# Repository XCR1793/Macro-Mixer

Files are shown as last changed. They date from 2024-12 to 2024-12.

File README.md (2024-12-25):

# Macro Mixer
A DIY Streamdeck alternative for a custom configurable macro board with dials, compatible with commercially available switches (Cherry MX Hotswappable). Reverse mounted under key lighting is also added for both debugging and aesthetics whilst allowing the top side of the board to remain clean and flush.

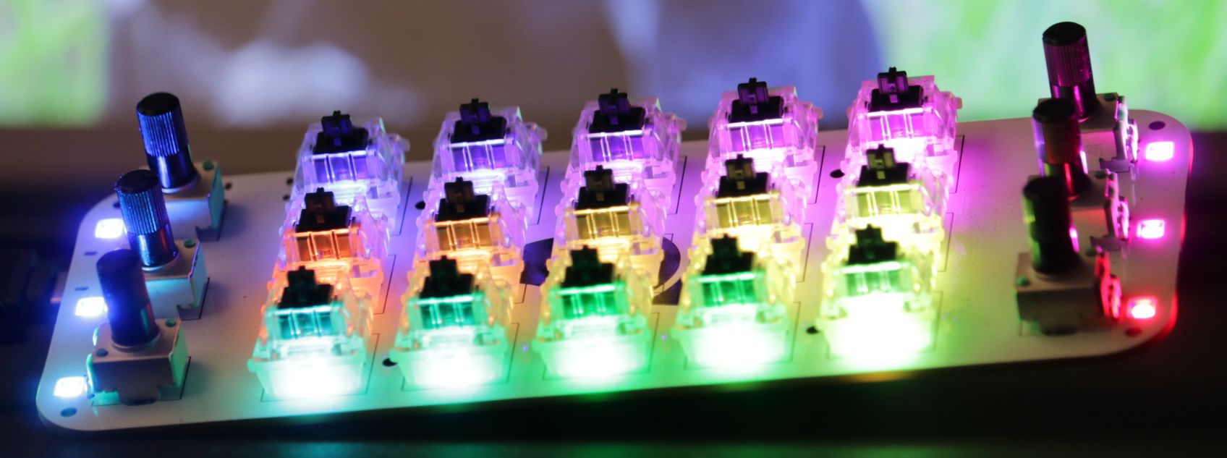
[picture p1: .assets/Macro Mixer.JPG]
Project_Image


## Features
* 15x Individually addressable n key rollover switches 
* 6x 12 bit resolution dials
* Addressable underglow lighting for every key and dial
* Easy Key assignment via the software

## [Hardware](/Hardware/README.md)
The case is 3D printed in white PLA plastic however other colour work too. The STLs and Steps are provided in the hardware folder.

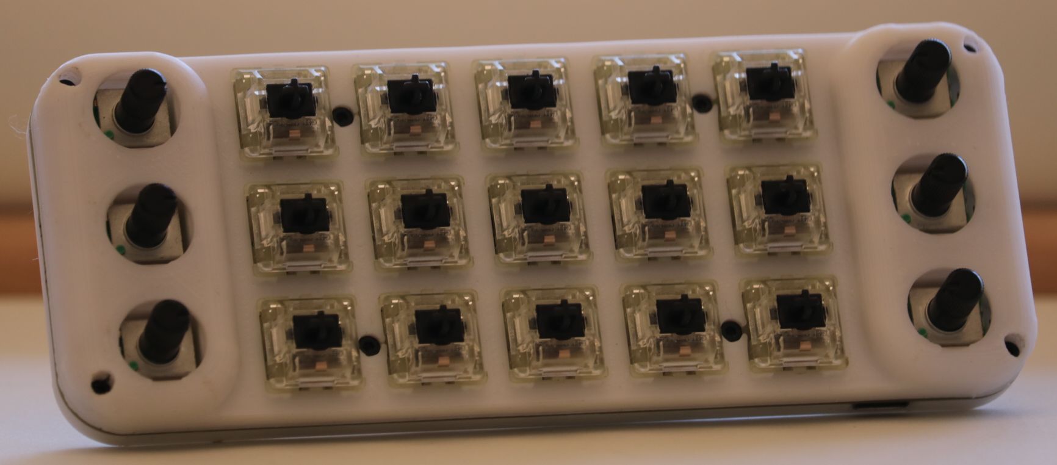
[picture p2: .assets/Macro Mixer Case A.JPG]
Hardware


## [Software](/Software/README.md)
Using PlatformIO and buildin ESP32 libraries, I have made an easy way to configure what keys are assigned to what key-combo.

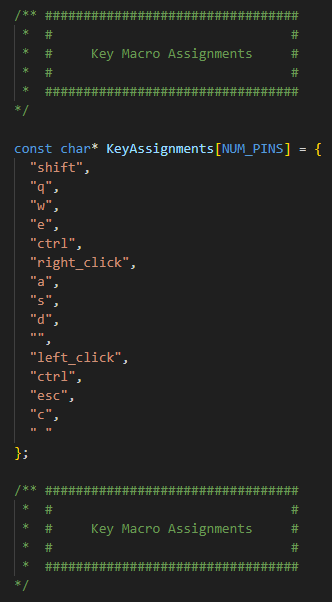
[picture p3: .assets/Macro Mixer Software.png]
Software


## [Embedded](/Embedded/README.md)
Although the currently fabricated PCB has some mistakes, I have modified the KiCAD files to account for this. The embedded circuit is a relatively dense board requiring a steady hand and hotplate.

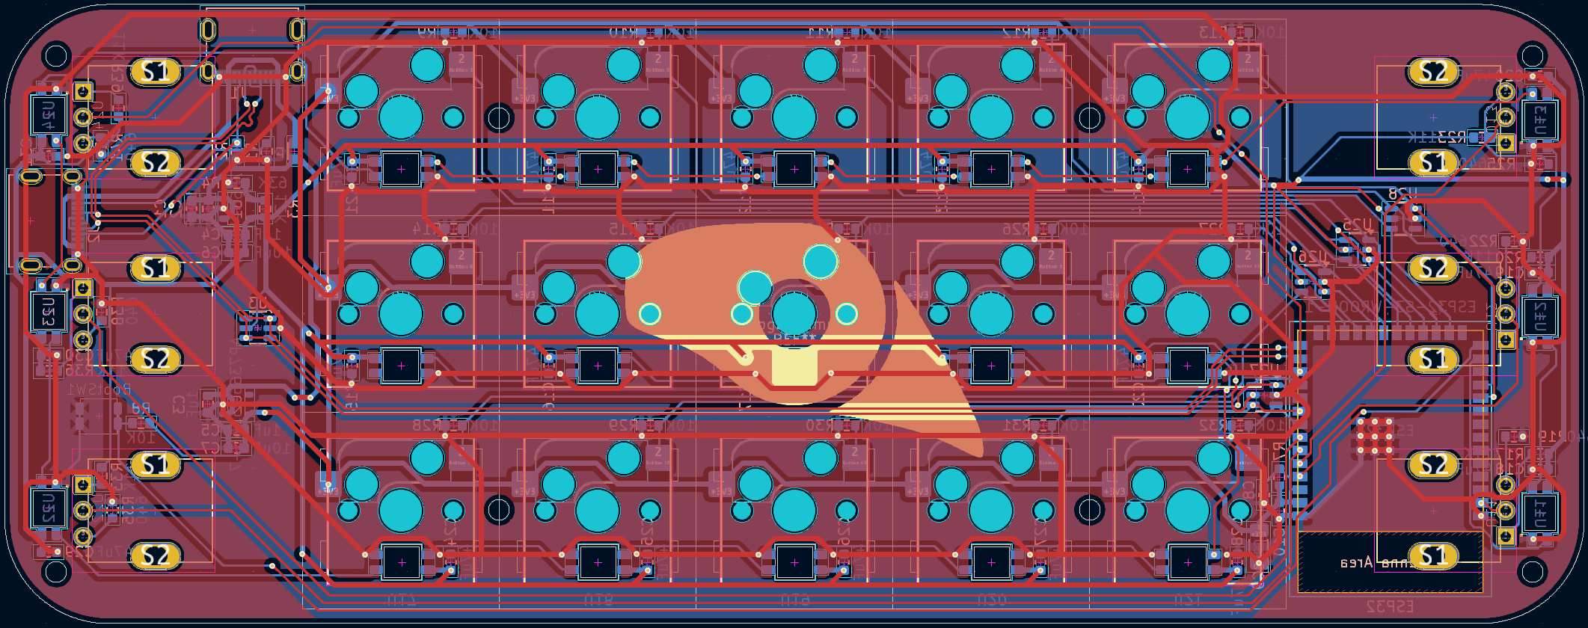
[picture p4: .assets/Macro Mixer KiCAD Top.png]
Embedded


## Roadmap
* Milestones: Completed Version 1.0
* Work In Progress: Easier software configuration
* Work In Progress: Potentiometers configuration
* Planned: Removing the boot button and using the switch as the the boot switch

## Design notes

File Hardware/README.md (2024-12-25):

# Macro Mixer - Hardware
A protective case which prevents esd, finger oils and dust from entering the pcb. The case also serves as great aesthetics. 8 Screws at M2 at 10mm screw length that sandwich the Top-PCB-Bottom stack. You have to put the switches in after assembling the hardware case as the case is designed for switches to sit ontop whilst being held by the Kalih Hotswappable Connectors.

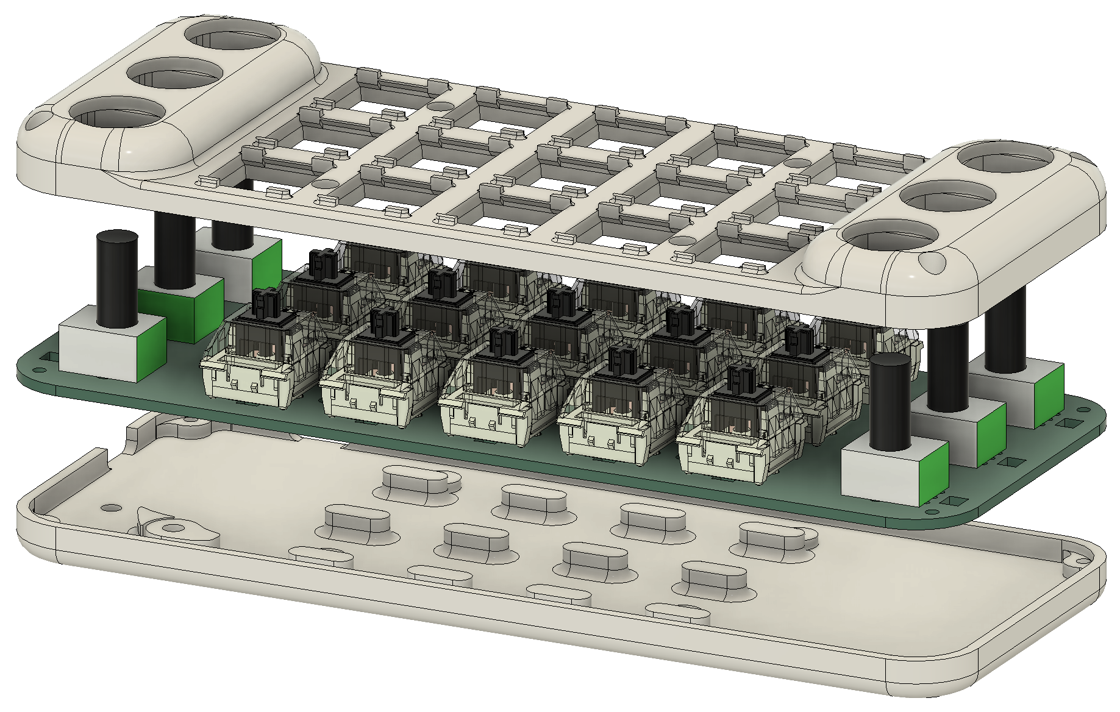
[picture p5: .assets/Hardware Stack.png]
Hardware_Stack

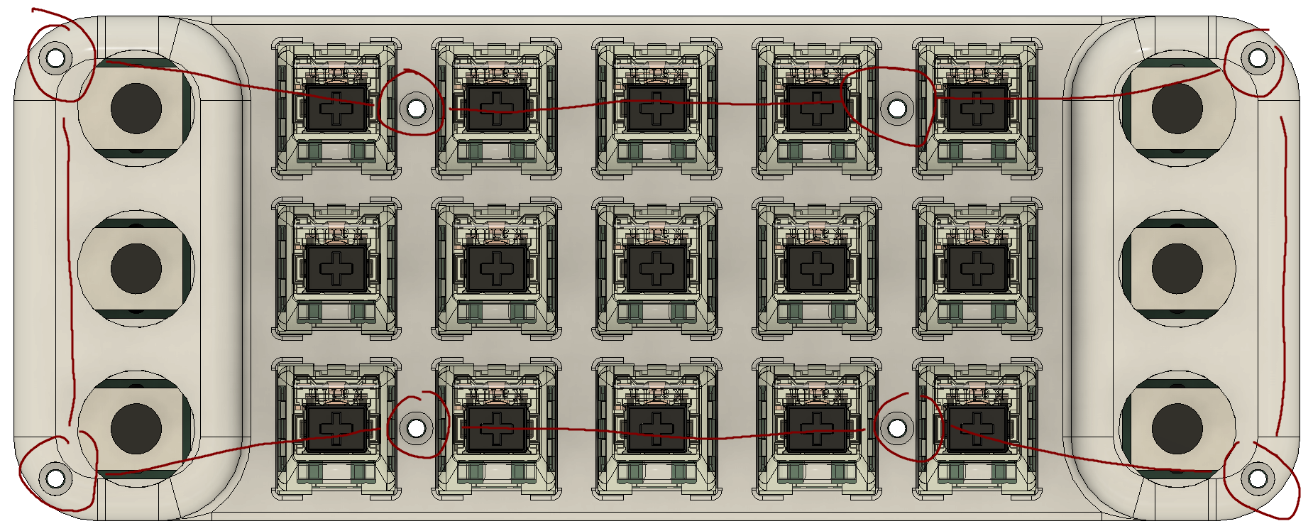
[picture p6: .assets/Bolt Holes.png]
Screw_Holes


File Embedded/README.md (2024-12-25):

# Macro Mixer - Embedded
The Wroom32 S3 module is the core of this build as there were just enough pins to hook up all n key rollover switches along with the 6 adc potentiometers. Currently there is a boot button which can be accessed through a hole at the bottom of the case and must be pressed whilst plugging in the board for it to enter boot mode. This will be changed in the future however for it to be the first key so this hole is no longer required and is less of a hastle to enter boot mode.

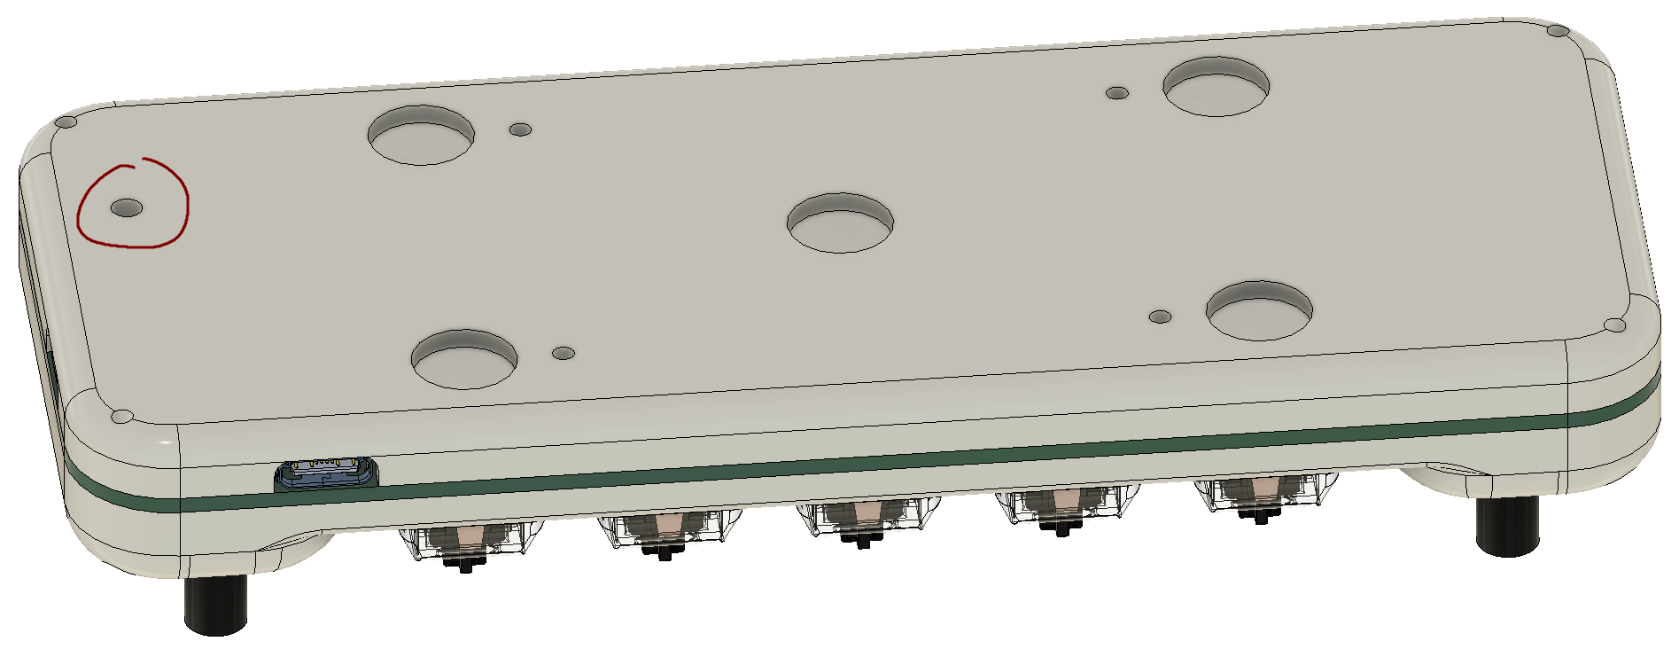
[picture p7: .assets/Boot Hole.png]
Boot_Hole


The Addressable LEDS are reverse mounted such that the top of the pcb will remain flush other than the soldered in potentiometers. This allows easy mounting of components such as the 3D printed case and other accessories that a user may customise their build with. The design of the circuit also allows all (except the potentiometers), to be placed on the bottom side of the pcb and be hotplatted in one go.

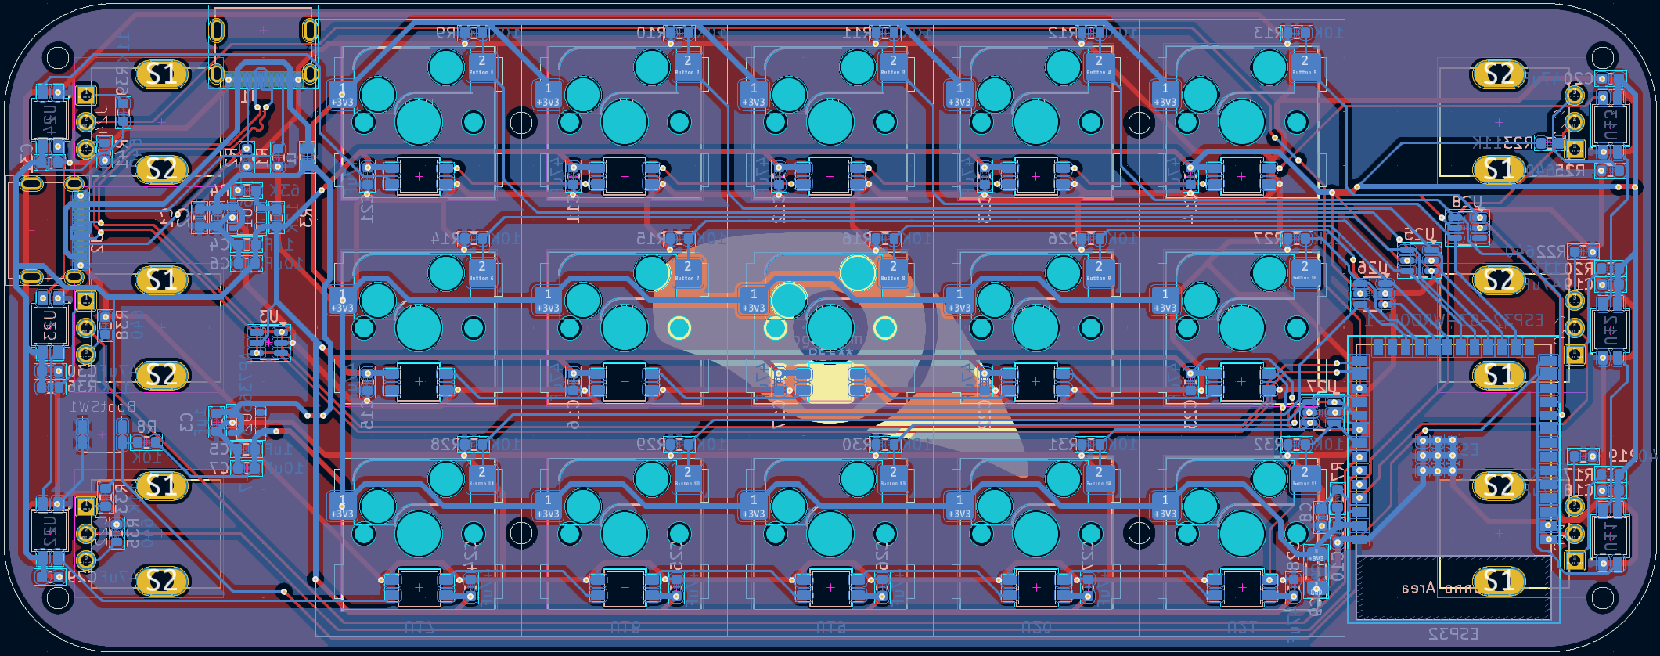
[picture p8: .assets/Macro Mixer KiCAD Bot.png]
Component_Placement


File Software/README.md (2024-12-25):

# Macro Mixer - Software
The software is relatively easy to configure, all you have to do is modify the [Serial_Array](/Software/src/main.cpp#L34) and replace one of the lines with your own custom key. The array must be of size 15 as there are 15 keys, note that the keys are maped from Top Left to Top Right is 1-5, Middle Left to Middle Right is 6-10, Bottom Left to Bottom Right is 11-15. If your not using a key, simpley do:
```cpp
"" // Make sure there is nothing inside it
```

To do Key combination, you have to do:
```cpp
"ctrl+c" // An example of the copy command
```

The software CURRENTLY DOES NOT SUPPORT multi key macros that include sets of multiple keys, however regular combinations such as control, alt or shift are available (Note that the FN key is not supported with the libraries I am using). Multi key macros like (w+d+s+s+s) will be implemented in the future.

Note: This is the KeyAssignment array that you need to modify.

Serial_Array

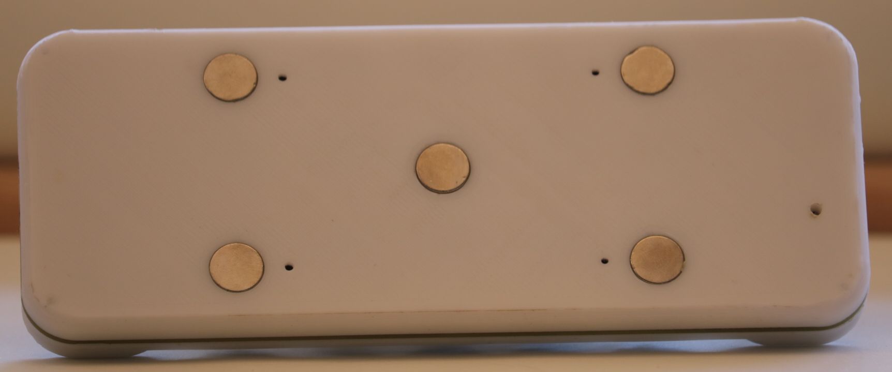
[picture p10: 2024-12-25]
.assets/Macro Mixer Case B.JPG

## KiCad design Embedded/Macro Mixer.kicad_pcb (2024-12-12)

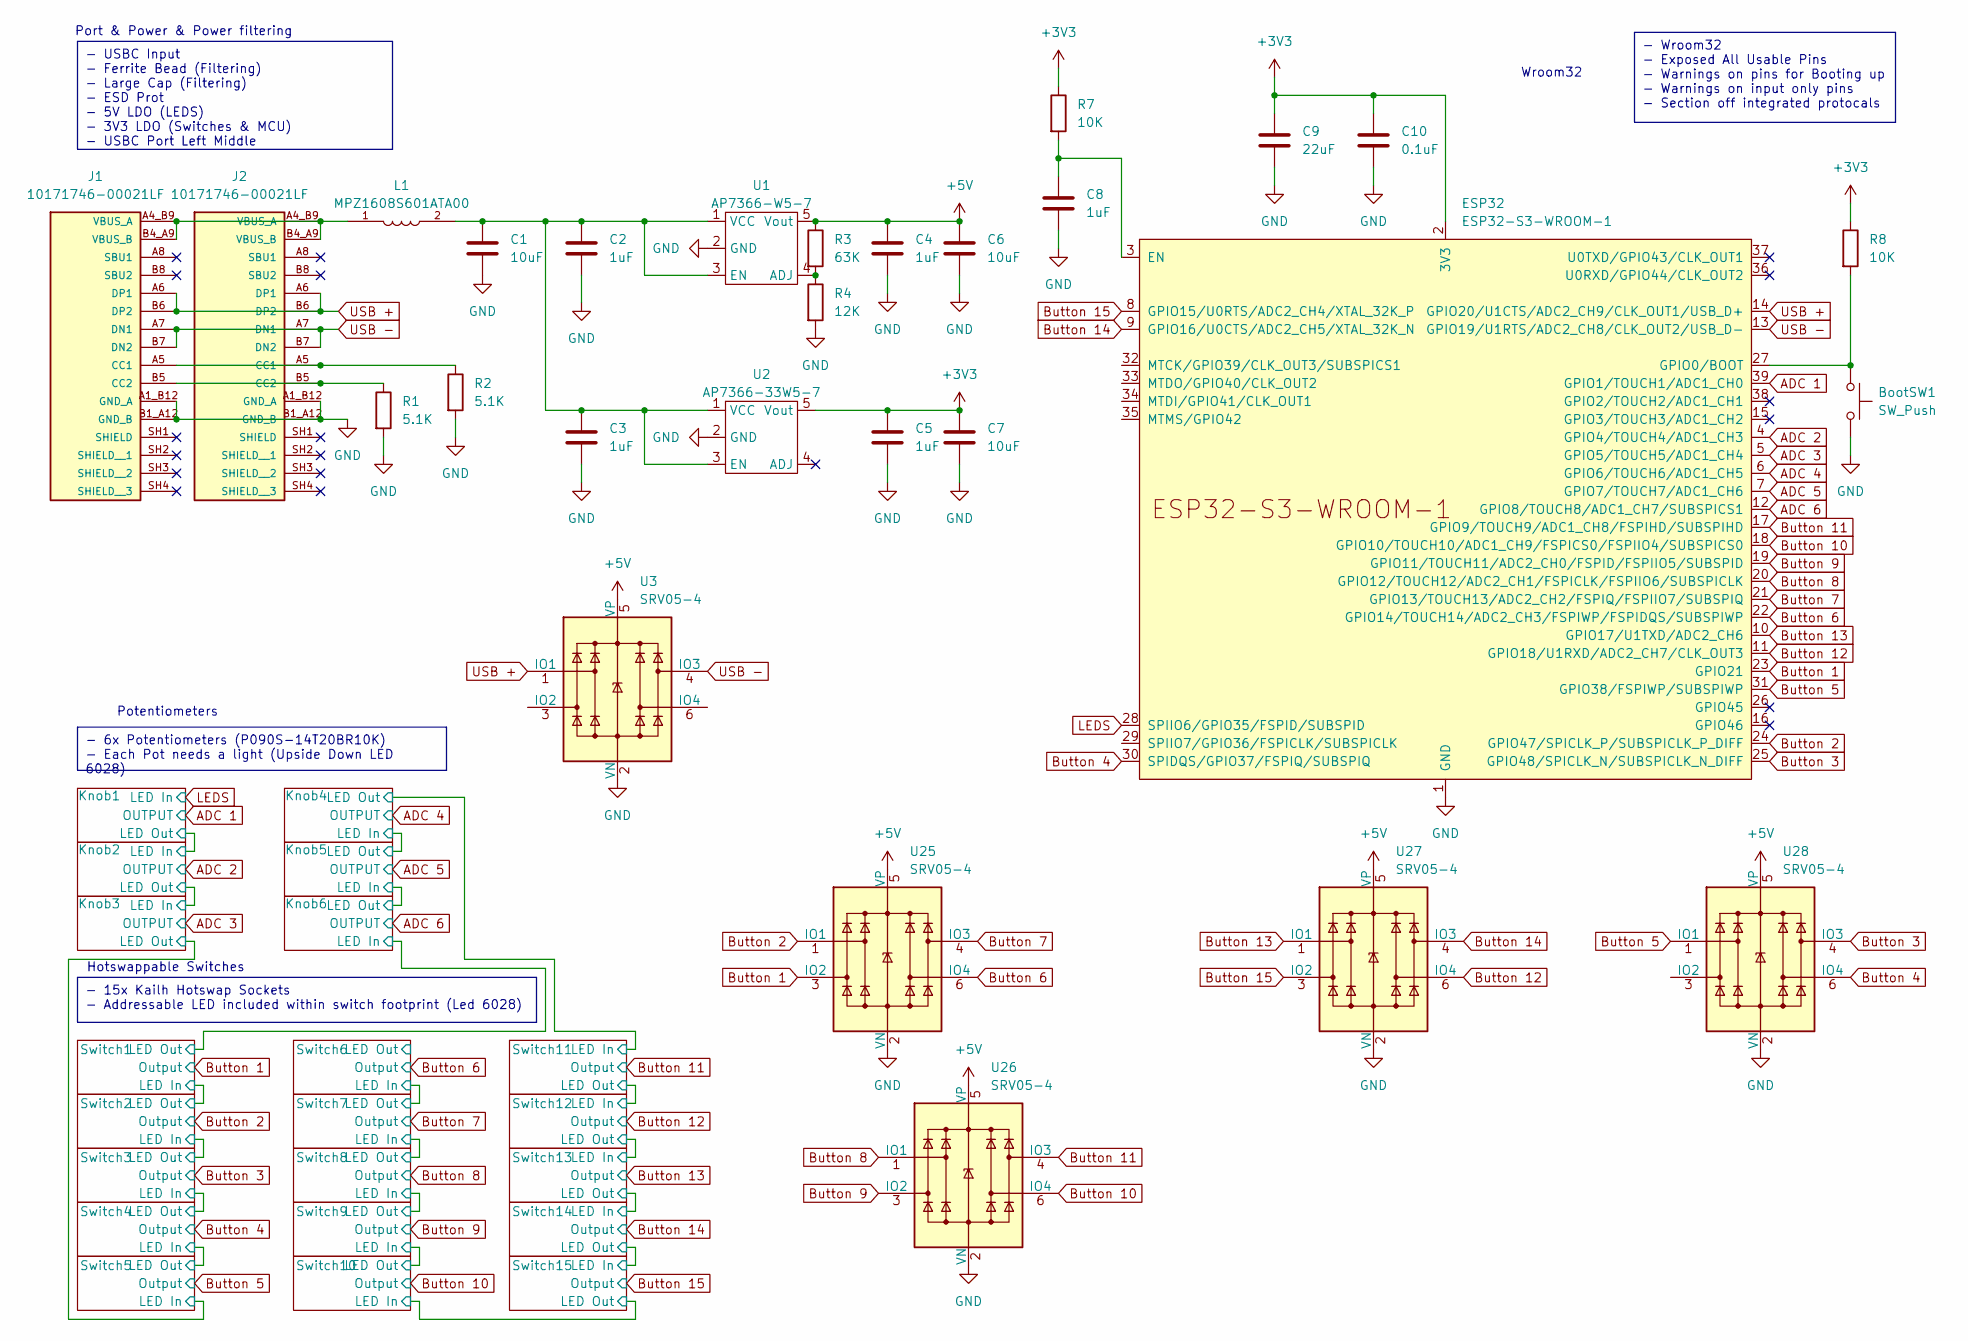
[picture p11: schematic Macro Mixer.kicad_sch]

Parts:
BootSW1: SW_Push; Button-R-667843
C1, C6, C7: 10uF; C_0603_1608Metric
C2, C3, C4, C5: 1uF; R_0603_1608Metric
C8: 1uF; C_0603_1608Metric
C9: 22uF; C_1206_3216Metric_Pad1.33x1.80mm_HandSolder
C10: 0.1uF; C_0603_1608Metric
ESP32: ESP32-S3-WROOM-1
J1, J2: 10171746-00021LF; AMPHENOL_10171746-00021LF; PARTREV A
L1: MPZ1608S601ATA00; INDC1608X95N
R1, R2: 5.1K; R_0603_1608Metric
R3: 63K; R_0603_1608Metric
R4: 12K; R_0603_1608Metric
R7, R8: 10K; R_0603_1608Metric
U1: AP7366-W5-7; AP7366
U2: AP7366-33W5-7; AP7366
U3, U25, U26, U27, U28: SRV05-4; SOT-23-6

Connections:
+3V3: C5.1, C7.1, C9.1, C10.1, ESP32.2 (3V3), R7.1, R8.1, U2.5 (Vout); also elsewhere on the board
+5V: C4.1, C6.1, R3.1, U1.5 (Vout), U3.5 (VP), U25.5 (VP), U26.5 (VP), U27.5 (VP), U28.5 (VP); also elsewhere on the board
ADC 1: ESP32.39 (GPIO1/TOUCH1/ADC1_CH0); also elsewhere on the board
ADC 2: ESP32.4 (GPIO4/TOUCH4/ADC1_CH3); also elsewhere on the board
ADC 3: ESP32.5 (GPIO5/TOUCH5/ADC1_CH4); also elsewhere on the board
ADC 4: ESP32.6 (GPIO6/TOUCH6/ADC1_CH5); also elsewhere on the board
ADC 5: ESP32.7 (GPIO7/TOUCH7/ADC1_CH6); also elsewhere on the board
ADC 6: ESP32.12 (GPIO8/TOUCH8/ADC1_CH7/SUBSPICS1); also elsewhere on the board
Button 1: ESP32.23 (GPIO21), U25.3 (IO2); also elsewhere on the board
Button 2: ESP32.24 (GPIO47/SPICLK_P/SUBSPICLK_P_DIFF), U25.1 (IO1); also elsewhere on the board
Button 3: ESP32.25 (GPIO48/SPICLK_N/SUBSPICLK_N_DIFF), U28.4 (IO3); also elsewhere on the board
Button 4: ESP32.30 (SPIDQS/GPIO37/FSPIQ/SUBSPIQ), U28.6 (IO4); also elsewhere on the board
Button 5: ESP32.31 (GPIO38/FSPIWP/SUBSPIWP), U28.1 (IO1); also elsewhere on the board
Button 6: ESP32.22 (GPIO14/TOUCH14/ADC2_CH3/FSPIWP/FSPIDQS/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), U25.6 (IO4); also elsewhere on the board
Button 7: ESP32.21 (GPIO13/TOUCH13/ADC2_CH2/FSPIQ/FSPIIO7/S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), U25.4 (IO3); also elsewhere on the board
Button 8: ESP32.20 (GPIO12/TOUCH12/ADC2_CH1/FSPICLK/FSPIIO6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), U26.1 (IO1); also elsewhere on the board
Button 9: ESP32.19 (GPIO11/TOUCH11/ADC2_CH0/FSPID/FSPIIO5/S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), U26.3 (IO2); also elsewhere on the board
Button 10: ESP32.18 (GPIO10/TOUCH10/ADC1_CH9/FSPICS0/FSPIIO4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), U26.6 (IO4); also elsewhere on the board
Button 11: ESP32.17 (GPIO9/TOUCH9/ADC1_CH8/FSPIHD/SUBSPIHD), U26.4 (IO3); also elsewhere on the board
Button 12: ESP32.11 (GPIO18/U1RXD/ADC2_CH7/CLK_OUT3), U27.6 (IO4); also elsewhere on the board
Button 13: ESP32.10 (GPIO17/U1TXD/ADC2_CH6), U27.1 (IO1); also elsewhere on the board
Button 14: ESP32.9 (GPIO16/U0CTS/ADC2_CH5/XTAL_32K_N), U27.4 (IO3); also elsewhere on the board
Button 15: ESP32.8 (GPIO15/U0RTS/ADC2_CH4/XTAL_32K_P), U27.3 (IO2); also elsewhere on the board
GND: BootSW1.2, C1.2, C2.2, C3.2, C4.2, C5.2, C6.2, C7.2, C8.2, C9.2, C10.2, ESP32.1 (GND), ESP32.40 (GND), ESP32.41 (GND), J1.A1_B12 (GND_A), J1.B1_A12 (GND_B), J2.A1_B12 (GND_A), J2.B1_A12 (GND_B), R1.2, R2.2, R4.2, U1.2 (GND), U2.2 (GND), U3.2 (VN), U25.2 (VN), U26.2 (VN), U27.2 (VN), U28.2 (VN); also elsewhere on the board
LEDS: ESP32.28 (SPIIO6/GPIO35/FSPID/SUBSPID); also elsewhere on the board
unnamed: C8.1, ESP32.3 (EN), R7.2
unnamed: BootSW1.1, ESP32.27 (GPIO0/BOOT), R8.2
unnamed: J1.A5 (CC1), J2.A5 (CC1), R2.1
unnamed: J1.B5 (CC2), J2.B5 (CC2), R1.1
unnamed: J1.A4_B9 (VBUS_A), J1.B4_A9 (VBUS_B), J2.A4_B9 (VBUS_A), J2.B4_A9 (VBUS_B), L1.1
unnamed: R3.2, R4.1, U1.4 (ADJ)
unnamed: C1.1, C2.1, C3.1, L1.2, U1.1 (VCC), U1.3 (EN), U2.1 (VCC), U2.3 (EN)
USB +: ESP32.14 (GPIO20/U1CTS/ADC2_CH9/CLK_OUT1/USB_D+), J1.A6 (DP1), J1.B6 (DP2), J2.A6 (DP1), J2.B6 (DP2), U3.1 (IO1)
USB -: ESP32.13 (GPIO19/U1RTS/ADC2_CH8/CLK_OUT2/USB_D-), J1.A7 (DN1), J1.B7 (DN2), J2.A7 (DN1), J2.B7 (DN2), U3.4 (IO3)

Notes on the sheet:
- 6x Potentiometers (P090S-14T20BR10K) - Each Pot needs a light (Upside Down LED 6028)
- USBC Input - Ferrite Bead (Filtering) - Large Cap (Filtering) - ESD Prot - 5V LDO (LEDS) - 3V3 LDO (Switches & MCU) - USBC Port Left Middle
- Wroom32 - Exposed All Usable Pins - Warnings on pins for Booting up - Warnings on input only pins - Section off integrated protocals
- 15x Kailh Hotswap Sockets - Addressable LED included within switch footprint (Led 6028)
Port & Power & Power filtering
Wroom32
Potentiometers
Hotswappable Switches

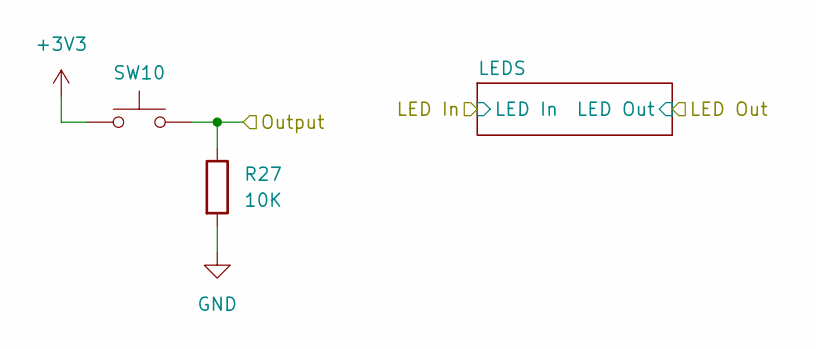
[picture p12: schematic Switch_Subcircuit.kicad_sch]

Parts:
R27: 10K; R_0603_1608Metric
SW10: Switch; Hotswap_MX_1.00u

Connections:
+3V3: SW10.1; also elsewhere on the board
Button 10: R27.1, SW10.2; also elsewhere on the board
GND: R27.2; also elsewhere on the board

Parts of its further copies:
R9, R10, R11, R12, R13, R14, R15, R16, R26, R28, R29, R30, R31, R32: 10K; R_0603_1608Metric
SW1, SW2, SW3, SW4, SW5, SW6, SW7, SW8, SW9, SW11, SW12, SW13, SW14, SW15: Switch; Hotswap_MX_1.00u

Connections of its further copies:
+3V3: SW1.1, SW2.1, SW3.1, SW4.1, SW5.1, SW6.1, SW7.1, SW8.1, SW9.1, SW11.1, SW12.1, SW13.1, SW14.1, SW15.1; also elsewhere on the board
Button 1: R9.1, SW1.2; also elsewhere on the board
Button 2: R10.1, SW2.2; also elsewhere on the board
Button 3: R11.1, SW3.2; also elsewhere on the board
Button 4: R12.1, SW4.2; also elsewhere on the board
Button 5: R13.1, SW5.2; also elsewhere on the board
Button 6: R14.1, SW6.2; also elsewhere on the board
Button 7: R15.1, SW7.2; also elsewhere on the board
Button 8: R16.1, SW8.2; also elsewhere on the board
Button 9: R26.1, SW9.2; also elsewhere on the board
Button 11: R28.1, SW11.2; also elsewhere on the board
Button 12: R29.1, SW12.2; also elsewhere on the board
Button 13: R30.1, SW13.2; also elsewhere on the board
Button 14: R31.1, SW14.2; also elsewhere on the board
Button 15: R32.1, SW15.2; also elsewhere on the board
GND: R9.2, R10.2, R11.2, R12.2, R13.2, R14.2, R15.2, R16.2, R26.2, R28.2, R29.2, R30.2, R31.2, R32.2; also elsewhere on the board

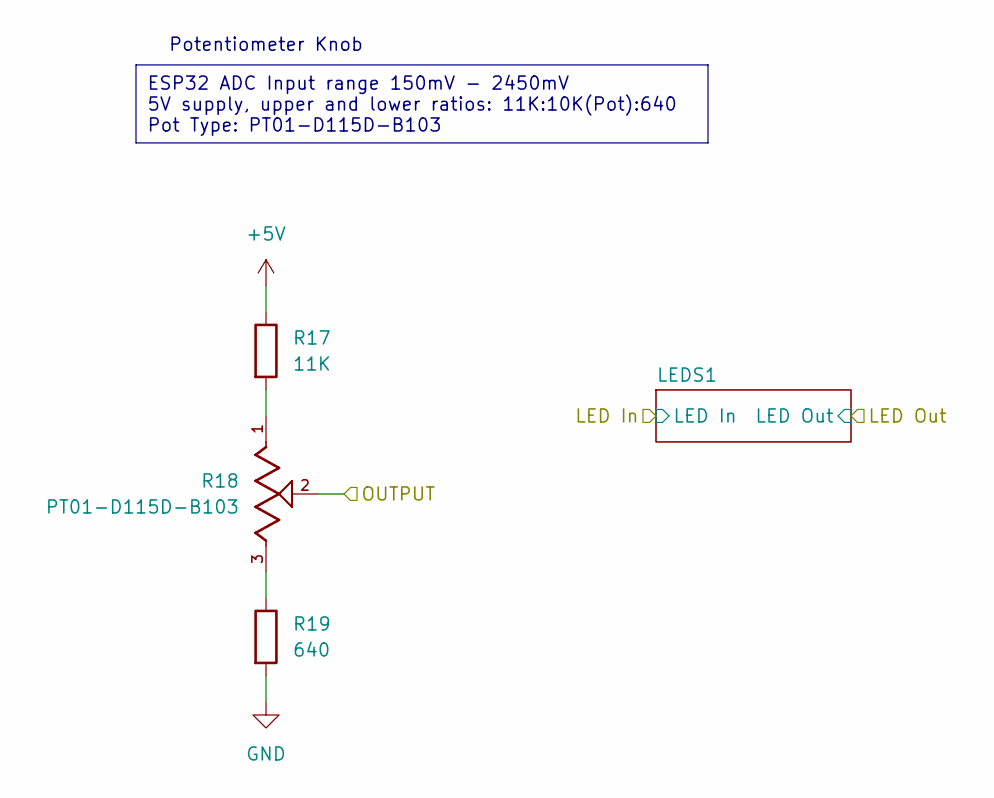
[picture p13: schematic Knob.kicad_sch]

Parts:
R17: 11K; R_0603_1608Metric
R18: PT01-D115D-B103; TRIM_PT01-D115D-B103; PARTREV 1.0
R19: 640; R_0603_1608Metric

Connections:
+5V: R17.1; also elsewhere on the board
ADC 1: R18.2; also elsewhere on the board
GND: R19.2; also elsewhere on the board
unnamed: R17.2, R18.1
unnamed: R18.3, R19.1

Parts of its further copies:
R20, R23, R33, R36, R39: 11K; R_0603_1608Metric
R21, R24, R34, R37, R40: PT01-D115D-B103; TRIM_PT01-D115D-B103; PARTREV 1.0
R22, R25, R35, R38, R41: 640; R_0603_1608Metric

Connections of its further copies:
+5V: R20.1, R23.1, R33.1, R36.1, R39.1; also elsewhere on the board
ADC 2: R21.2; also elsewhere on the board
ADC 3: R24.2; also elsewhere on the board
ADC 4: R34.2; also elsewhere on the board
ADC 5: R37.2; also elsewhere on the board
ADC 6: R40.2; also elsewhere on the board
GND: R22.2, R25.2, R35.2, R38.2, R41.2; also elsewhere on the board
unnamed: R20.2, R21.1
unnamed: R21.3, R22.1
unnamed: R23.2, R24.1
unnamed: R24.3, R25.1
unnamed: R33.2, R34.1
unnamed: R34.3, R35.1
unnamed: R36.2, R37.1
unnamed: R37.3, R38.1
unnamed: R39.2, R40.1
unnamed: R40.3, R41.1

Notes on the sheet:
ESP32 ADC Input range 150mV - 2450mV 5V supply, upper and lower ratios: 11K:10K(Pot):640 Pot Type: PT01-D115D-B103
Potentiometer Knob

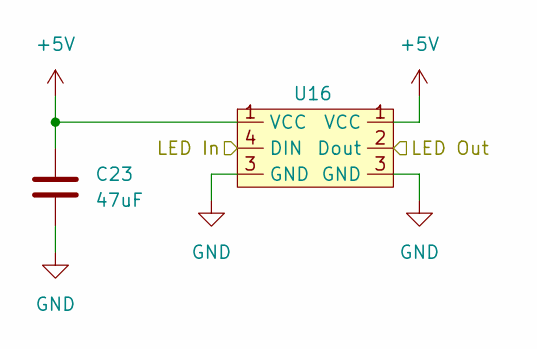
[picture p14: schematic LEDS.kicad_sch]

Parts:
C23: 47uF; C_0603_1608Metric
U16: 6028_Reverse_Mount

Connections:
+5V: C23.1, U16.1 (VCC); also elsewhere on the board
/Switch10/LED In: U16.4 (DIN); also elsewhere on the board
/Switch10/LED Out: U16.2 (Dout); also elsewhere on the board
GND: C23.2, U16.3 (GND); also elsewhere on the board

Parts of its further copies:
C11, C12, C13, C14, C15, C16, C17, C18, C19, C20, C21, C22, C24, C25, C26, C27, C28, C29, C30, C31: 47uF; C_0603_1608Metric
U4, U5, U6, U7, U8, U9, U10, U11, U12, U13, U14, U15, U17, U18, U19, U20, U21, U22, U23, U24: 6028_Reverse_Mount

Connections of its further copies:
+5V: C11.1, C12.1, C13.1, C14.1, C15.1, C16.1, C17.1, C18.1, C19.1, C20.1, C21.1, C22.1, C24.1, C25.1, C26.1, C27.1, C28.1, C29.1, C30.1, C31.1, U4.1 (VCC), U5.1 (VCC), U6.1 (VCC), U7.1 (VCC), U8.1 (VCC), U9.1 (VCC), U10.1 (VCC), U11.1 (VCC), U12.1 (VCC), U13.1 (VCC), U14.1 (VCC), U15.1 (VCC), U17.1 (VCC), U18.1 (VCC), U19.1 (VCC), U20.1 (VCC), U21.1 (VCC), U22.1 (VCC), U23.1 (VCC), U24.1 (VCC); also elsewhere on the board
/Knob1/LED Out: U11.2 (Dout), U12.4 (DIN)
/Knob2/LED Out: U12.2 (Dout), U13.4 (DIN)
/Knob3/LED Out: U7.4 (DIN), U13.2 (Dout)
/Knob4/LED In: U22.4 (DIN), U23.2 (Dout)
/Knob4/LED Out: U17.4 (DIN), U22.2 (Dout)
/Knob5/LED In: U23.4 (DIN), U24.2 (Dout)
/Knob6/LED In: U14.2 (Dout), U24.4 (DIN)
/Switch1/LED In: U4.2 (Dout), U14.4 (DIN)
/Switch2/LED In: U4.4 (DIN), U5.2 (Dout)
/Switch3/LED In: U5.4 (DIN), U6.2 (Dout)
/Switch4/LED In: U6.4 (DIN), U7.2 (Dout)
/Switch6/LED In: U8.4 (DIN), U9.2 (Dout)
/Switch6/LED Out: U8.2 (Dout)
/Switch7/LED In: U9.4 (DIN), U10.2 (Dout)
/Switch8/LED In: U10.4 (DIN), U15.2 (Dout)
/Switch10/LED In: U21.2 (Dout); also elsewhere on the board
/Switch10/LED Out: U15.4 (DIN); also elsewhere on the board
/Switch11/LED Out: U17.2 (Dout), U18.4 (DIN)
/Switch12/LED Out: U18.2 (Dout), U19.4 (DIN)
/Switch13/LED Out: U19.2 (Dout), U20.4 (DIN)
/Switch14/LED Out: U20.2 (Dout), U21.4 (DIN)
GND: C11.2, C12.2, C13.2, C14.2, C15.2, C16.2, C17.2, C18.2, C19.2, C20.2, C21.2, C22.2, C24.2, C25.2, C26.2, C27.2, C28.2, C29.2, C30.2, C31.2, U4.3 (GND), U5.3 (GND), U6.3 (GND), U7.3 (GND), U8.3 (GND), U9.3 (GND), U10.3 (GND), U11.3 (GND), U12.3 (GND), U13.3 (GND), U14.3 (GND), U15.3 (GND), U17.3 (GND), U18.3 (GND), U19.3 (GND), U20.3 (GND), U21.3 (GND), U22.3 (GND), U23.3 (GND), U24.3 (GND); also elsewhere on the board
LEDS: U11.4 (DIN); also elsewhere on the board

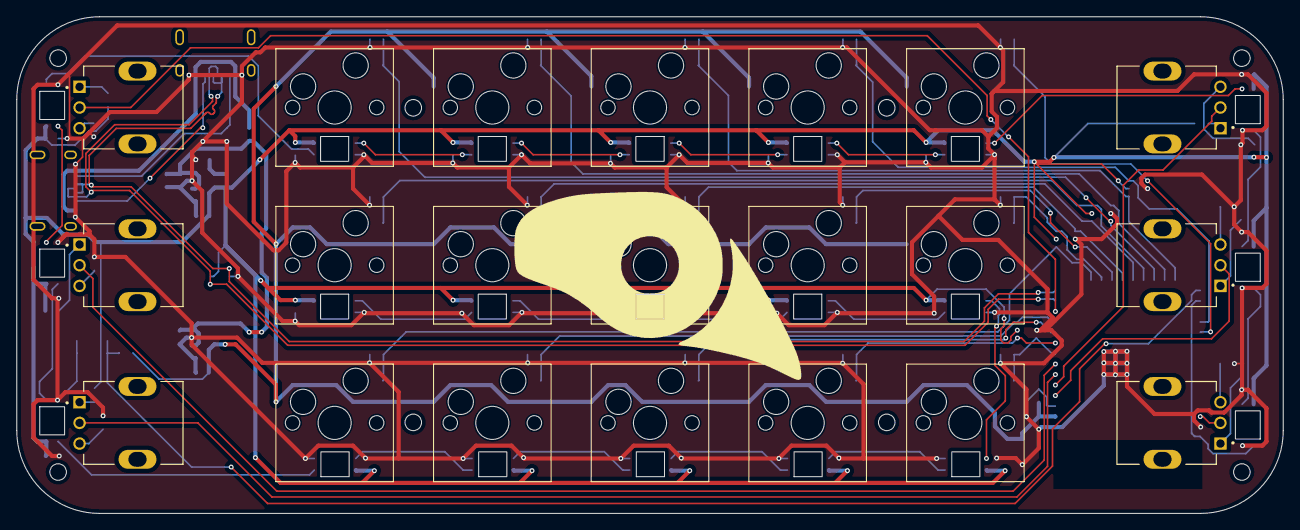
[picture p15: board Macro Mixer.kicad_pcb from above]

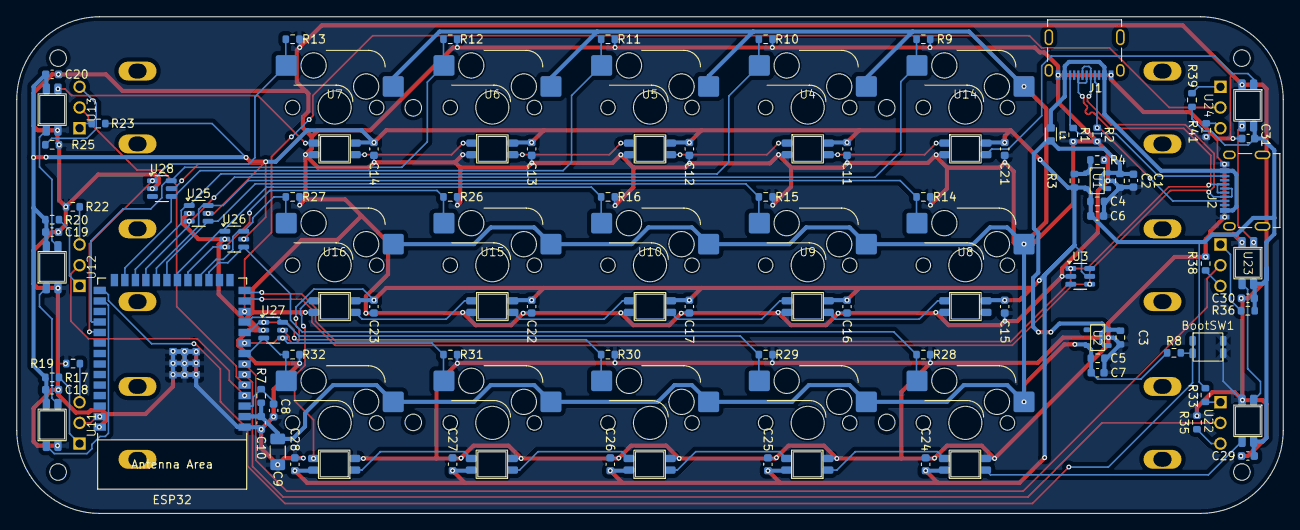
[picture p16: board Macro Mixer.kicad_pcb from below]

Board: 2 copper layers, 153.0 x 60.0 mm, 118 parts (97 on the bottom side), 66 nets.

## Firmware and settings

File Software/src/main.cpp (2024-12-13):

#include <Arduino.h>
#include <FastLED.h>
#include <USB.h>
#include <USBHIDKeyboard.h>
#include <USBHIDMouse.h>

#define led_pin 35
#define led_count 21

CRGB leds[led_count];

// L: 8, 7, 6
// R: 5, 4, 1
// Row Top: 21, 47, 48, 37, 38
// Row Mid: 14, 13, 12, 11, 10
// Row Bot: 9 , 18, 17, 16, 15
int pins[] = {1, 4, 5, 38, 37, 48, 47, 21, 8, 7, 6, 9, 18, 17, 16, 15, 10, 11, 12, 13, 14};

#define NUM_PINS (sizeof(pins) / sizeof(pins[0]))

// Create USB HID Keyboard instance
USBHIDKeyboard keyboard;

// Create USB HID Mouse instance
USBHIDMouse mouse;

/** #################################
 *  #                               #
 *  #     Key Macro Assignments     #
 *  #                               #
 *  #################################
*/

const char* KeyAssignments[NUM_PINS] = {
  "shift",
  "q",
  "w",
  "e",
  "ctrl",
  "right_click",
  "a",
  "s",
  "d",
  "",
  "left_click",
  "ctrl",
  "esc",
  "c",
  " "
};

/** #################################
 *  #                               #
 *  #     Key Macro Assignments     #
 *  #                               #
 *  #################################
*/

void sendKeyCombination(const char* combination) {
  String combStr = String(combination);
  int start = 0, idx;
  String keys[3]; // Max of 3 keys in a combination
  int keyCount = 0;

  // Check for mouse actions first
  if (combStr == "left_click") {
    mouse.click(MOUSE_LEFT);
    return;
  } else if (combStr == "right_click") {
    mouse.click(MOUSE_RIGHT);
    return;
  } else if (combStr == "middle_click") {
    mouse.click(MOUSE_MIDDLE);
    return;
  }

  // Parse keyboard combination string by '+'
  while ((idx = combStr.indexOf('+', start)) != -1 && keyCount < 3) {
    keys[keyCount++] = combStr.substring(start, idx);
    start = idx + 1;
  }
  keys[keyCount++] = combStr.substring(start);

  // Send keyboard keys
  for (int i = 0; i < keyCount; i++) {
    if (keys[i] == "ctrl") {
      keyboard.press(KEY_LEFT_CTRL);
    } else if (keys[i] == "alt") {
      keyboard.press(KEY_LEFT_ALT);
    } else if (keys[i] == "shift") {
      keyboard.press(KEY_LEFT_SHIFT);
    } else if (keys[i] == "esc") {
      keyboard.press(KEY_ESC);
    } else if (keys[i].length() == 1) { // Single character key
      keyboard.press(keys[i][0]);
    }
  }
}

void releaseKeyCombination(const char* combination) {
  String combStr = String(combination);
  int start = 0, idx;
  String keys[3];
  int keyCount = 0;

  while ((idx = combStr.indexOf('+', start)) != -1 && keyCount < 3) {
    keys[keyCount++] = combStr.substring(start, idx);
    start = idx + 1;
  }
  keys[keyCount++] = combStr.substring(start);

  for (int i = 0; i < keyCount; i++) {
    if (keys[i] == "ctrl") {
      keyboard.release(KEY_LEFT_CTRL);
    } else if (keys[i] == "alt") {
      keyboard.release(KEY_LEFT_ALT);
    } else if (keys[i] == "shift") {
      keyboard.release(KEY_LEFT_SHIFT);
    } else if (keys[i] == "esc") {
      keyboard.release(KEY_ESC);
    } else if (keys[i].length() == 1) {
      keyboard.release(keys[i][0]);
    }
  }
}


// Pin Mapper
int mapPinValue(int pin) {
  if (pin >= 0 && pin <= 4) {
    // Map 0 to 4 to 4 to 0
    return 4 - pin;
  } else if (pin >= 10 && pin <= 14) {
    // Map 10 to 14 to 5 to 9
    return 19 - pin;
  } else if (pin >= 5 && pin <= 9) {
    // Map 5 to 9 to 10 to 14
    return pin + 5;
  }
  // If the pin is out of the expected range, return the same value
  return pin;
}


// Initialise Variables
signed int internalDelay[NUM_PINS] = {};
signed int pressdelay = 25; // ################# Synchronised Timing delay in ms #################

void setup(){
  // Enable Serial
  Serial.begin(115200);

  // Initialise All Pins
  for(size_t i = 0; i < led_count; i++){
    pinMode(pins[i], INPUT);
  }

  // Begin Keyboard Library
  keyboard.begin();

  // Begin USB Library
  USB.begin();

  // Initialise Addressable LEDs
  FastLED.addLeds<WS2812, led_pin, GRB>(leds, led_count);

  // Everything Loaded Confirmation
  Serial.println("USB Keyboard Initialised");
}

void loop(){
  signed int pin = 0;
  for(size_t i = 0; i < NUM_PINS; i++){
    if((pins[i] >= 1 && pins[i] <= 5) || (pins[i] >= 6 && pins[i] <= 8)){
      pin--;
      // Read Potentiometer Values Here
    }else if(digitalRead(pins[i])){
      // if((pin <= sizeof(KeyAssignments)) && (internalDelay[i] <= 0)){ // Switch the if statment below with this one to enable synchronised timing
      if(pin <= sizeof(KeyAssignments)){ // Switch this with above to enable synchronised timing
        Serial.println(KeyAssignments[mapPinValue(pin)]);
        sendKeyCombination(KeyAssignments[mapPinValue(pin)]);
        // internalDelay[i] = pressdelay; // Enable this to Allow the keys to set timers (REQUIRED FOR SYNCHRONISED TIMING)
      }
    }else if(!digitalRead(pins[i])){
      releaseKeyCombination(KeyAssignments[mapPinValue(pin)]);
    }
    pin++;
  }
  // for(size_t i = 0; i < NUM_PINS; i++){ // This is required to count the timer for Synchronised Timing
  //   internalDelay[i] = internalDelay[i] - 1;
  //   if(internalDelay[i] <= 0){
  //     internalDelay[i] = 0;
  //   }
  // }
  delay(1);
}
